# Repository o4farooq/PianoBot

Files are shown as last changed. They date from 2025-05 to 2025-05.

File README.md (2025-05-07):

# PianoBot 🎹 – Autonomous Piano-Playing Robot

PianoBot is an autonomous, LEGO-based robot capable of playing piano keys by interpreting color-coded sheet music. Designed and programmed by a team of three engineering students, the robot combines precise mechanical design, sensor integration, and custom CAD components to achieve smooth and accurate performance.

## 🔧 Overview

- 🎯 **Accuracy:** 92% success rate across 70 notes  
- 🤖 **Actuation:** Two robotic fingers driven by motors and 4 LEGO gears  
- 📏 **Precision Control:** Ultrasonic sensor ensures accurate key strike distance  
- 🎨 **Sheet Music Detection:** Color sensor reads and decodes color-coded notes  

## 🛠️ Key Features

- **Sensor Integration:**  
  Combines an ultrasonic sensor for dynamic range detection and a color sensor to parse visual sheet music input.

- **Mechanical Design:**  
  Robotic fingers with a 75-degree range of motion, powered by 2 motors and supported by a gear train, enabling controlled key presses.

- **Custom Components:**  
  CAD-modeled robotic fingers, motor mounts, and suction rollers designed in **SolidWorks** and **AutoCAD**, then fabricated via **laser cutting** and **3D printing**.

## 📐 Technologies Used

- **SolidWorks / AutoCAD** – Design and modeling of structural components  
- **Arduino (UNO R4)** – Microcontroller for sensor input and motor control  
- **C++ / ROBOTC** – Codebase for logic and motion control  
- **3D Printing / Laser Cutting** – Manufacturing of custom-designed robot parts  

## 🧠 Team & Purpose

This project was developed by a team of three second-year Mechanical Engineering students at the **University of Waterloo** as part of a robotics design challenge. The focus was on blending hardware design, motion control, and sensor feedback in a compact and functional prototype.

## 🔗 License

This project is open for educational and portfolio purposes. All CAD files and source code belong to the original team members.

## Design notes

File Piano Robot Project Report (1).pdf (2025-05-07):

# Piano Robot Project Report

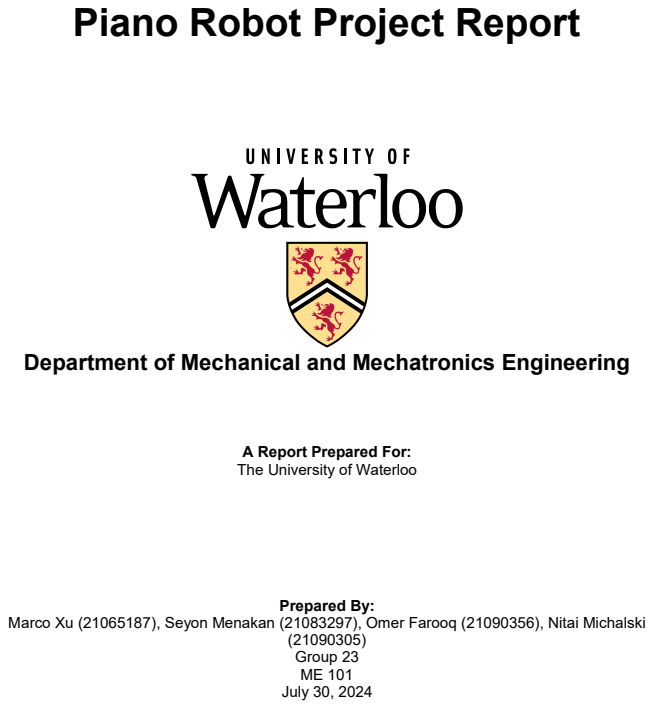
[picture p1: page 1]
Prepared By:; (21090305) Group 23 ME 101 July 30, 2024

Department of Mechanical and Mechatronics Engineering

A Report Prepared For:
The University of Waterloo

Marco Xu (21065187), Seyon Menakan (21083297), Omer Farooq (21090356), Nitai Michalski

## Table of Contents

List of Tables | Error! Bookmark not defined.

## List of Figures

Figure 17: Sheet music motor holder. The SolidWorks model can be found in appendix B, figure

Figure 18: Sheet music suck roller. SolidWorks model can be found in appendix B, figure 36. ..19 Figure 19: Sheet music compressive rollers. The SolidWorks model can be found in appendix B,

Figure 20: Bracket holding the two-color sensors. The AutoCAD model can be found in

Figure 51: Sketches of the suck roller (roller 1), tensioning roller (roller 2), and motor mount ....48

## Summary

This report covers the development of an autonomous robot designed to play the piano using an

EV3 robot controller and a color sensor to read sheet music. The primary goal of this project

was to create a robot that could read sheet music and play two octaves of a piano while staying under a $100 budget (excluding the EV3 robot cost). This document details the project’s

background, problem definition, technical progress, mechanical and software design,

verification, and project management. The motivation behind the robot was to showcase the

EV3 robot’s capabilities while creating a challenging project. The robot was designed to read

sheet music using color sensors, save played songs, and accurately press piano keys. The engineering specifications included cost constraints, safety, note-playing delay, sheet music

reading accuracy, and ease of setup. The final design featured a compact mechanism with color

sensors, a conveyor belt for feeding sheet music, and robotic fingers for pressing the keys.

During the conceptual design phase, the team brainstormed various solutions for the subfunctions of reading sheet music, saving songs, and pressing piano keys. The final design

combined the most feasible solutions, such as a fixed color sensor with rotating sheet music

and robotic fingers controlled by motors. Detailed sketches and CAD models ensured accurate and efficient mechanical design. Verification tests confirmed that the robot met all primary

functional requirements, including playing notes with minimal delay, accurately reading sheet

music, and effectively handling user input. The software design included functions for

configuring sensors, storing and reading note values, and controlling the robotic fingers. The project management section highlighted task delegation and adherence to the project plan.

Recommendations for future improvements included ensuring identical gears for the right finger,

making the design more symmetrical and visually appealing, using a larger keyboard, upgrading

motors for better performance, and enhancing the user interface for a more interactive experience. These enhancements would further improve the robot’s functionality, reliability, and

user experience. In conclusion, the project successfully achieved its objectives, and the report

outlines the next steps for continued development.

## 1.0 Needs Analysis

1.1 Background Description

The project aimed to create an autonomous piano playing system for the EV3 robot, capable of

playing notes on a keyboard based on sheet music. The robot would be able to save and play

songs, appealing to anyone who understands music, and presenting a challenging programming

and design challenge.

1.2 Needs Statement

A need exists for a robot to play all white keys of 2 octaves of a keyboard/piano while costing under $100 without including the cost of EV3 robot and any other given components. The

primary functional requirement is to play 2 full octaves of the keyboard from the low “C” note to the high “C” note. The primary constraint requirement is to build the piano robot with the given components and any extra components giving a total cost of under $100. The budgeting and

cost tracking will be highlighted in a later section.

1.3 Engineering Specification
Each specification is carefully designed to ensure the project meets its functional, safety, and

performance requirements [1]. The Engineering Design Specification for the project encompasses ten critical characteristics. Firstly, the cost is constrained to be less than $100.00

CAD, which will be verified through analysis by totaling the receipts of any additional expenses.

Secondly, safety is a key constraint and is paramount; it is verified through demonstrations to

ensure there are no pointy edges, pinch points, or potential fire hazards. Thirdly, a functional requirement is that the system must play notes with minimal delay, specifically less than one

second. This characteristic will be tested using a stopwatch to measure the delay between key

presses, calculating the difference between the highest and lowest delays. Furthermore, the

ability to play modified sheet music will be examined by having an experienced pianist cross-check if the notes are played correctly. Another functional requirement is for the sheet music

reader to read the color sensor combinations with an 80% accuracy at least which can be

verified by outputting the notes onto a .txt file or onto the console and having someone cross-

check with the predetermined color sensor combinations. A functional requirement that must be considered is the range of the notes being played, which is from Low C to High C. This is

exactly two octaves and only the white keys will be played. This can be verified from making the

robot play the C major scale on two octaves, which will therefore hit every key from Low C to

High C. A non-functional requirement for the system is that it should be easy to set up. The

robot should be assembled every time without damage to the components, and without any of the components falling out of place. A functional requirement to consider is the maximum

amount of notes the robot can play, which is limited to 70 notes. This is because as the robot

plays notes using over a longer period, the robot becomes more and more inaccurate with the

angles needed to hit each individual key. This can be verified by making the robot play a .txt file with over 70 notes and see if the robot completely stops playing at 70 notes. Moreover, user

input is also a functional requirement to increase the robot’s enjoyability. The design can

accomplish this by using button controls that manipulate the robot’s functions. This is verified

through demonstration of how pressing the buttons controls the actions of the robot. The final requirement is the constraint requirement of the mass of the robot weighing less than 3 kg. This

can be verified by using a scale to measure the entirety of the robot.

## 2.0 Conceptual Design

2.1 Morphological Matrix

Figure 1: Morphological Matrix

The piano robot’s subfunctions include reading sheet music, saving the song as a.txt file, and

pressing piano keys with robotic fingers. Three solutions were considered: vertical color sensors, horizontal and vertical sensors, and fixed sensors. The chosen solutions balanced

efficiency, cost, and complexity, ensuring the robot could effectively read sheet music.

2.2 Conceptual Designs Considered

These three designs were the conceptual ones formulated during the initial stages of the design

process. Each design contributed various components that were incorporated into the final

product. However, it primarily utilizes the most effective concepts from conceptual designs 2 and 3, which eventually resulted in the final product.

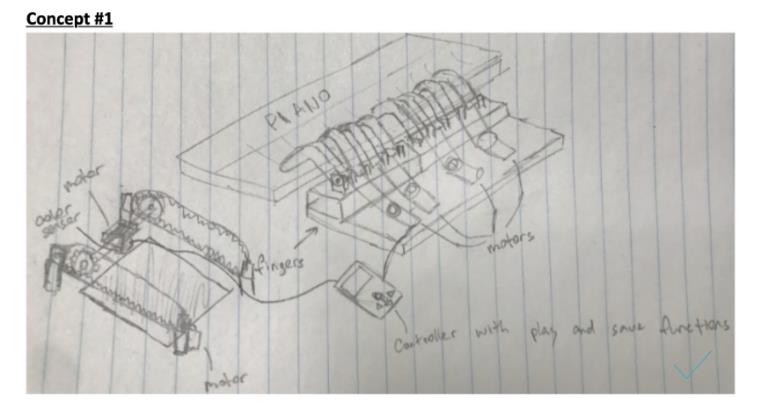
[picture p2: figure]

Figure 2: Conceptual Design 1

The first conceptual design was the inspiration for the sheet music reader. More specifically, the

drawing shows a design utilizing suction rollers to roll the sheet music beneath the color sensor.

The color sensor reads the colors on the sheet music and translates them into notes to be

played by the robotic hand. Furthermore, the fingers of this design are not accurate to the final design, as it consists of multiple fingers, while the final design only has two fingers. This is one

main difference between the conceptual design and the final product. Finally, the controller in

this conceptual design was used for the same purpose in the final design, which was to operate

and save songs that were already played.

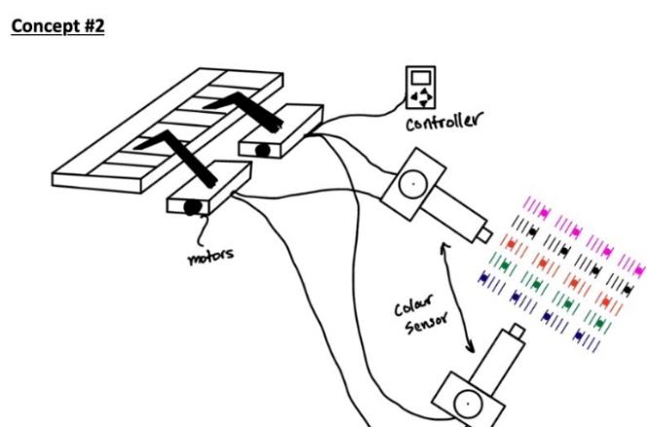
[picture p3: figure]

Figure 3: Conceptual Design 2

The second conceptual design served as the inspiration for the robot’s fingers. The final product mirrored this design, featuring two separate robotic fingers, each supported by two motors and

controlled through the controller. This configuration allowed for precise and independent

movements of each finger, enhancing the robot’s ability to perform complex tasks. Furthermore,

the color reader, which was part of this design, proved to be somewhat accurate in its function. However, it didn’t include specifications for the suction roller and conveyor belt design used for

the sheet music, which were later incorporated into the final design of the robot. These

additional components were essential for the accurate handling and processing of sheet music,

ensuring smooth operation. Overall, this conceptual design was primarily used for robotic fingers, significantly influencing the development of the final product and contributing to its

overall functionality and effectiveness.

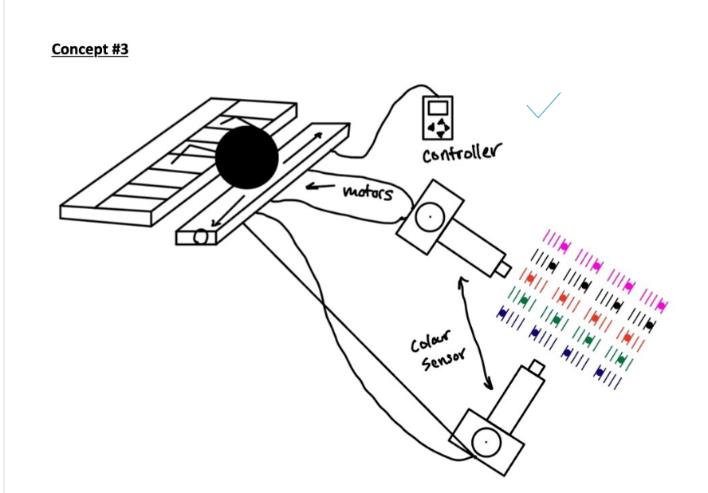
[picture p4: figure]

Figure 4: Conceptual design 3

The final conceptual design proved impractical due to the difficulty of creating a rolling mechanism

that kept the robotic fingers in place for accurate key strikes. Balancing the mobility of the base with the stability and precision of the fingers was complex. Maintaining smooth and consistent

motion without the fingers shifting was essential for accuracy, making the design challenging to implement and impractical for real-world application without significant modifications.

2.3 Decision Making Matrix

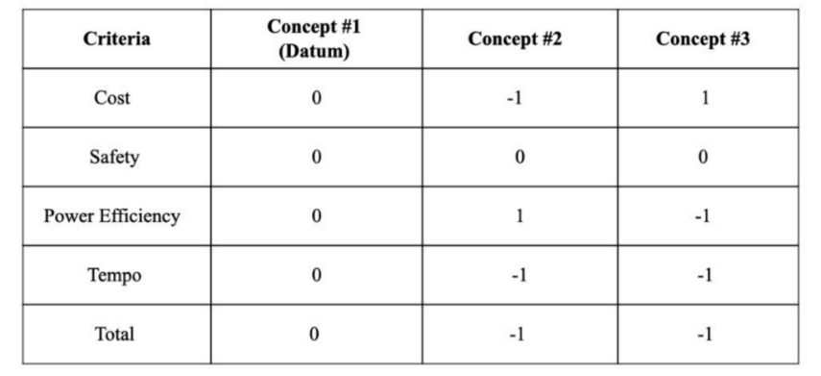
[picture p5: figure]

Figure 5: Decision Making Matrix

The decision-making matrix essentially evaluates the feasibility of each conceptual design by

ranking each important requirement (e.g., cost, safety, etc.). It ranks each requirement based on

the following criteria: +1 being better, 0 being mediocre, and -1 being not as good. Moreover, the total score is summed up at the end, and the conceptual design with the highest score is expected

to be the most feasible.

From the above, conceptual design 1 is the most feasible as it has the highest score of zero, while the two other conceptual designs both got a score of negative one. However, the final decision

was made to proceed with the second conceptual design for the note-playing section of the robot

because the first conceptual design was too simple. As for the robot’s music reader section, a

new design was needed as the current designs may be too difficult to do and limit the sheet music’s size. This new design will be detailed in the next section.

2.4 Updated Mechanism Designs
For the sheet music reader part of the robot, a new design was created with a compact Tetrix

frame, where a motor, mounted to the Tetrix frame, turned a suck roller. This suck roller would

pull in the sheet music, assisted with two free-rolling rollers which would keep the sheet music

properly tensioned. A color sensor bracket would hold two color sensors in place, which would read the sheet music as it is being pulled by the suck roller. This design can be seen below, in

figure 6.

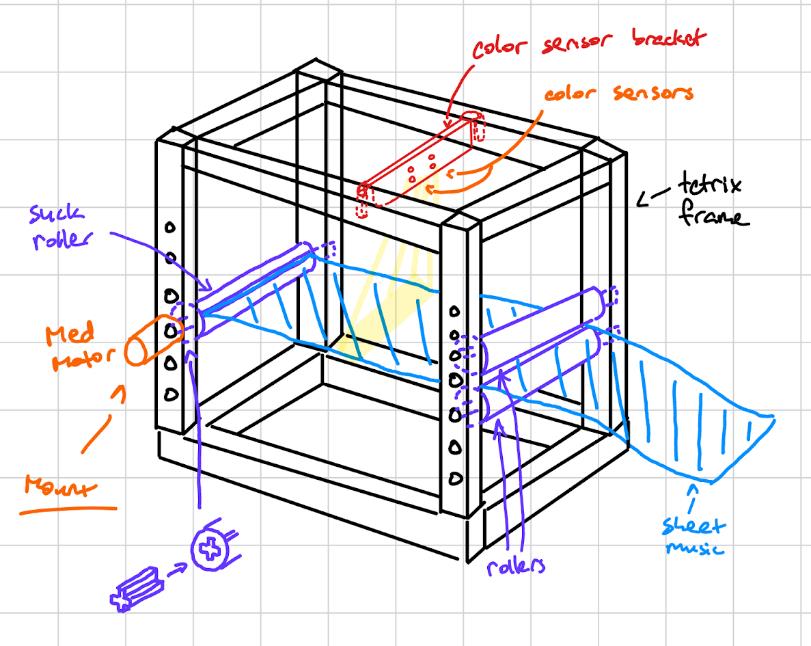
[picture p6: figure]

Figure 6: New sheet music reader design

For the note-playing part of the robot, a more detailed design of the arm movement mechanisms

was created, as seen in figure 7. There would be one motor to control the horizontal rotation of

the arm (to move to different keys) and another motor to control the vertical rotation of the arm (to press down on the key). The horizontal rotation motor had a gear attached to it, which

meshed with another gear, which had an arm mount/base attached to it. This arm mount/base

held the arm (with a gear attached to it), along with the vertical rotation motor (with a gear

attached to it). This meant the vertical rotation motor would rotate horizontally with the arm while it is operating.

Figure 7: Design of the arm movement mechanisms

Additionally, a recalibration system was to be implemented. Two ideas were considered for the

recalibration method: an ultrasonic sensor for each arm to detect the distance of the arm as it rotates, or a touch sensor for each arm to detect when the arm reaches a certain point.

Ultimately, it was decided that the touch sensor method would be more reliable as the ultrasonic

sensor could pick up unreliable readings due to the way the arm rotates. The recalibration

function would involve the arm rotating until it pressed the touch sensor, at which point, the robot would know the exact position of the arm and would re-position the arm in its starting

position.

2.5 Individual Part Designs
Sketches were made for parts that needed to be 3D-printed or laser-cut (appendix E), which

included the suck roller, tensioning rollers, motor mount, color sensor bracket, and fingers.

These sketches provided a rough starting idea for the CAD design and only had some rough dimensions.

For the tensioning rollers, the pegs at the ends of the roller were meant to fit in the Tetrix holes

and be able to freely rotate. The size of the rollers was chosen so that two rollers next to each

other in the Tetrix frame would result in a very small gap.

The suck roller had the same dimensions as the tensioning rollers, except for two changes: a

slot for sheet music and a cross-shaped hole on the end of one of the pegs for a Lego axle to be inserted in. The cross-shaped hole would allow the motor to connect to the suck roller and

rotate it.

The motor mount was designed to serve two purposes: hold the motor in place and mount to the

Tetrix frame securely. Only a rough concept sketch of the motor mount was created; the actual

design of the motor mount was to be adjusted during the CAD modelling stage.

For the color sensor bracket, it needed to be able to fit on the Tetrix frame without moving. Two pieces at the ends of the bracket would be inserted into the Tetrix frame holes. In the middle of

the bracket, there would be four holes for the color sensors to mount to.

For the finger, a realistic finger shape was desired. Some cross-shaped holes were included so

that it could be attached to the arm mount/base. The finger should also be thin so that it can play between the black keys.

## 3.0 Mechanical Design

3.1 Layout
The primary robot, designed using Lego and laser-cut parts, holds a piano and presses its keys. It has two individual Lego beams that pivot sideways while also moving up and down

vertically to hit the piano keys. These arms are powered by two sets of motors and gear

systems for each robotic finger. As seen below in figure 8, the larger motors and gears on the

base control the rotation of the robotic arms along the horizontal axis. These motors are connected to a rectangular base and two rectangular prisms as shown in figure 9. Supporting

beams secure the motors to the axle, and the right arm has one side of the robot also includes

an additional stopper to limit the finger’s vertical motion of the finger upwards. On the other

design, the finger’s upward motion is limited beyond a certain point by the bottom edge of the finger, as it presses against the base of the axle holder on the rotating structure. This is visible

in figure 10:

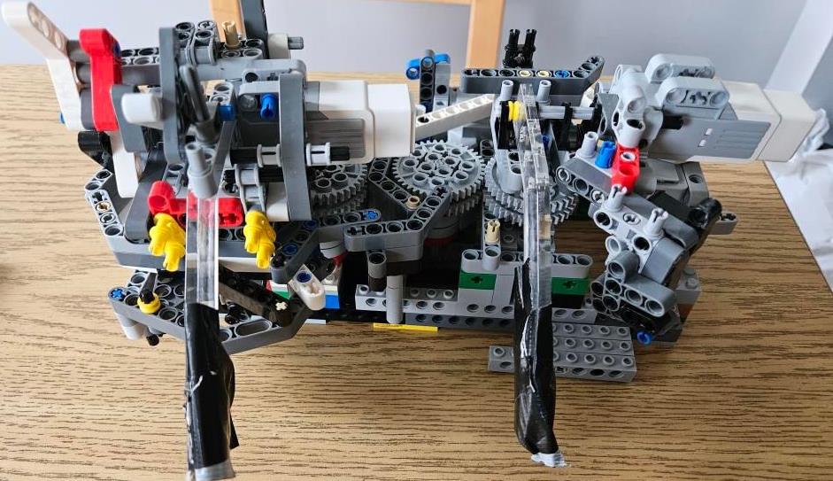
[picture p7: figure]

Figure 8: Top view of piano-player

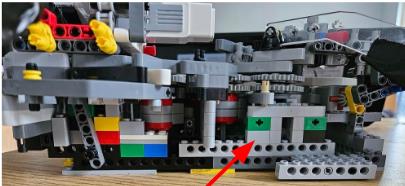
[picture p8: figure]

Figure 9: Front view of piano-player showing the rectangular base

Figure 10: Side view of finger axle

The gear attached to the motor is held tightly in place with the gear attached to the moving

structure through Lego walls that push them together from each side. The rotating base that

houses the finger is attached to one of the gears, which allows the finger to move in an arc between each key. Each moveable base also includes a smaller motor attached directly to the axle which moves the fingers up and down to press each key. This design allows the motors to

be rigidly attached and provide enough downward force. As shown in figure 11, the robot fingers themselves were laser cut from acrylic, which provided high strength while also being relatively

light. This allowed the fingers to withstand the higher forces required to press down some of the

further keys at wider angles. The fingers were also cut to angles and lengths to press down

each key with maximum force, while also limiting its range of motion past the necessary requirements to hit the furthest keys. Piece of cardboard were also duct taped to the edges of

the fingers to remove the unpleasant noise that resulted from the acrylic striking the keyboards

plastic keys. These fingers included cross-shaped cuts in the exact shape of the axle to fit

tightly, with small tolerances. This allowed the fingers to be powered by the motor attached to the axle from the other side, while remaining rigid when higher power was used on the motor. In

front of the robot is a rectangular base that holds the piano in place. As shown in figure 12, the

user can easily place the piano in the correct spot during each use by placing the piano in a way

that holes on each piano fit into cylindrical Lego prices from each corner. This ensures the piano is placed in a position that allows the fingers to reach each key.

Figure 11: Robotic finger. The AutoCAD model can be found in appendix B, figure 40.

Figure 12: Robot piano base

One of the issues in the original design was the rigidity of the moveable base structure, and its

ability to withstand reaction forces that resulted from pressing down each key. When the robot

attempted to press down certain keys, especially further ones at larger angles, the base holding

the finger and its base would move upwards, instead of pressing the keys downwards. This was solved using two separate methods. Firstly, the gear attached to the base structure that held the

finger and its motor was attached to an axle, which was then fed through 2 different holes through pieces attached to the main base that held the gear structure. The base gear and axle

structure are shown in figure 13. Also, the axle was held in place from moving up or down using

a small Lego axle holder and a small, but thick, unused Lego gear that fit tightly on the axle.

This ensured that the gear was held in place, and only rotated, without any up or down movements off its base. After the moveable base itself was secured tightly, the finger and axle

attached to the base also needed to be secured, since they moved upwards when the keys

were pressed down. This was accomplished by building a guide rail around each of the rotating

bases, attached to the bottom base of the robot. Extruding Lego pieces were then added to the moveable bases which moved on top of the guide rail. This ensured that the upwards reaction

force from pressing down the keys were counteracted by the guide rail that held in place the

base and the finger attached to them. These components are highlighted in figures 14 and 15.

This improved rigidity allowed the robot to completely press down the keys, while also using less motor power, since less energy was lost through movements within the robot itself.

Figure 13: Gear and axle for rotating base

Figure 14: Guide rail on the outer side

Figure 15: Extrusion that moves along guide rail

For the music sheet reader, a cube-like design was created with four vertical beams on each

side, as shown in figure 16, and described in the previous section. Unlike robotic arms, this

design was built using Tetrix parts, as well as laser cut, and 3D printed components. In this

design, a motor was used to turn a 3D printed conveyor belt which took the fed paper sheet music in a thin slot. The motor was attached to the frame using the holder show in figure 17.

This suck roller was alongside two free-rolling rollers that helped keep the sheet music properly

tensioned and aligned in place for the color sensors. The suck roller and compressive rollers are

shown in figures 18 and 19. These two color sensors were attached to the frame using a laser cut bracket that fit into the Tetrix frame, shown in figure 20. This allowed the two color sensors

to be positioned to read the left and right sides of the sheet music, while also being properly

tensioned to keep the colored sheet music straight, while also feeding at the appropriate speed.

Figure 21 shows the sheet music being fed into the sheet music reader.

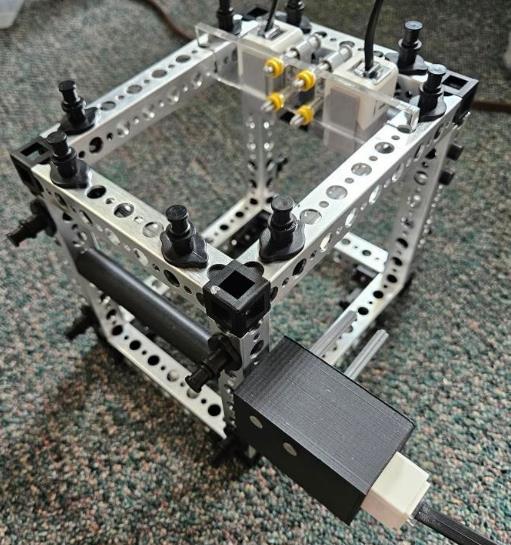
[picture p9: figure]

Figure 16: Music sheet reader

Figure 17: Sheet music motor holder. The SolidWorks model can be found in appendix B, figure 37.

Figure 18: Sheet music suck roller. SolidWorks model can be found in appendix B, figure 36.

Figure 19: Sheet music compressive rollers. The SolidWorks model can be found in appendix B, figure 36.

Figure 20: Bracket holding the two-color sensors. The AutoCAD model can be found in

appendix B, figure 39.

Figure 21: Sheet music reader pulling in sheet music.

3.2 Functions

There are a multitude of functions for the piano robot that all need to be met for it to successfully

operate. Furthermore, the functions of this robot were generalized into 6 main functional

requirements that had to be met for a successful final product. These included:

i. The robot should be able to successfully play the notes with minimal time delay
ii. | The robot should be able to read and play the colored sheet music
iii. | The robot reads in the color sensor combinations successfully
iv. | The robot should have a range of notes that spans roughly two octaves
v. The maximum amount of notes a robot can play in a song should be 70

vi. The robot should be able to handle user input successfully (via the EV3 controller)

The robotic fingers’ ability to move between notes quickly (Function I) was achieved through a

lightweight design and precise angle measurements. The conveyer belt design for the sheet

music (Function II) allowed the color sensor to register each note, with software ensuring accurate note correspondence. The optimal speed for the sheet music to roll beneath the color

sensor (Function III) was found using suction rollers to impose tension. Stability of the robotic

arms (Function IV) was ensured by the pivot of the gears, arm length, and a stable Lego base.

The note-reading limit (Function V) was enforced through software, tested with a 70-note song. Finally, a straightforward coding solution (Function VI) generated a user interface on the EV3

controller for saving, playing, or exiting the program.

## 4.0 Verification of Design

4.1 Line by Line Verification
The following table consists of the engineering design specification and the method of testing for

each specification.
Table

Table 1: Line by Line Verification of Engineering Design

No. | Characteristic | Relation | Value | Units | Verification Method | Comments
1 | Cost | < | 100 | $, CAD | Analysis | Total the receipts of additional costs
2 | Safety | N/A | N/A | N/A | Analysis | Ensure there are no pinch points, pointy edges, or potential fire hazards
3 | Plays notes with minimal delay | < | 1 | s | Test | Use a stopwatch to measure minimal delay between each key press, then take the difference between the highest and lowest delays
4 | Plays modified sheet music | N/A | N/A | N/A | Examination | Have an experienced pianist listen to the played notes and verify that the robot is playing the correct notes
5 | Reads the color sensor combinations accurately | ≥ | 80 | % | Test | Output the notes read from the sheet music reader onto a .txt file or onto the robot’s console cross-check with the predetermined color sensor
6 | Range of notes | = | 2 | octaves | Test | Make the robot play the C major scale on two octaves, which will therefore hit every key from Low C to High C

7 | Easy setup | N/A | N/A | N/A | Demonstration | While assembling the robot, show that the system is assembled every time without damage to the components, and any components falling out of place
8 | Maximum amount of notes the robot can play in a song | = | 70 | notes | Test | Make the robot play a .txt file with over 70 notes and see if the robot completely stops playing at 70 notes
9 | Robot includes user input | N/A | N/A | N/A | Demonstration | Have volunteers press buttons on the robot to control its actions which will therefore display user input
10 | Mass of the entirety of the robot | < | 3 | kg | Test | Use a scale to measure the entirety of the robot

The verification results are as follows:
1) After totaling all receipts, the final cost is $44.00 which is well below the maximum cost

planned for this project

2) After running through the robot’s physical mechanism, there are no pinch points, pointy

edges or potential fire hazards that came across the PianoBot
3) After taking measurements using the stopwatch, the highest delay was 0.94 seconds

and lowest delay was 0.52 seconds, giving a delay well under 1 second

4) After running modified sheet music through the sheet music reader, the PianoBot was

able to play those corresponding notes
5) After making the robot read the sheet music, the group calculated the number of notes

that were correctly read and divided it by the total notes that were read. This gave a

value of 87%, which was over the target of 80%
6) After testing the robot with the C major scale, it was shown to play 2 full octaves from

Low C to High C

7) After countless times of setting the robot up, it was time and time again demonstrated

that none of the components slipped off or broke

8) After making the robot read a .txt file with over 70 notes, the robot only played 70 and stopped after the 70th note, proving the test correct
9) After having volunteers test out the robot on demo day, the user input aspect is fulfilled

using buttons either playing a different .txt file or saving read notes into a .txt file

10) After weighing the entire robot structure, the total mass came out to be 1.947 kg which is

well under 3 kg.

4.2 Assessment of Verification
After running through all the verification tests for all functional requirements, non-functional

requirements, and constraint requirements, it is safe to say that the design works as it passed all the tests and fulfilled all requirements. While it does not play the piano or read the notes with

100% accuracy, it fulfilled all predetermined goals and therefore is a success.

## 5.0 Software Design and Implementation

5.1 Overall Software Operation

The software operates by starting with the user pressing the enter button, recalibrating the arm, and then prompting the user to press a button. If the button is pressed for under 3 seconds, the

sheet music reader plays the music, if it's held for 3 seconds or more, the note values are saved,

and the program shuts down. The flow chart in the Appendix explains the process.

5.2 Robot Task List

The robot task list is as follows:

Startup:

- Configure all sensors.
- Run arm re-calibration function.
- Arm spins until a touch sensor is hit, ensuring the position of the arm is calibrated.
- Display on controller screen: “Press enter button to play music from sheet music. Press up/down/left/right buttons to play saved music. To exit the program, hold the enter button.”

Operation:

- User presses the enter button.
- Turn on the motor that connects to the suck roller.
- Two colour sensors detect two colours from the sheet music, which are translated into a note value that is associated with an angle for the arm motors to rotate.
- An arm motor rotates so that the finger hovers over the note that corresponds to the colour combination detected by the colour sensors.
- When a certain colour combination is detected (eg. black and black), this means the song has ended
- Display on controller screen: “Hold up/down/left/right buttons to save the song. Press up/down/left/right buttons to play saved music. Press enter button to play music from sheet music. To exit the program, hold the enter button.”
- If any of the up/down/left/right buttons are held:
- Save the note values into a text file.
- Display on the controller: “Song saved to up/down/left/right button slot.”
- Display on controller screen: “Hold up/down/left/right buttons to save the song. Press up/down/left/right buttons to play saved music. Press enter button to play music from sheet music. To exit the program, hold the enter button.”
- If any of the up/down/left/right buttons are pressed:
- Read the note values from the associated text file and play the song.
- A finger motor rotates so that the finger presses down on the note, then rotates the opposite way so that the finger returns to its previous position.
- The robot will run the arm re-calibration function
- Display on controller screen: “Hold up/down/left/right buttons to save the song. Press up/down/left/right buttons to play saved music. Press enter button to play music from sheet music. To exit the program, hold the enter button.”

Shutdown Procedure:

- If the enter button is held:
- Display on controller screen: “Skee-yee” and “EEEEEE”
- Exit the program.

5.3 How Overall Code was Separated

The code was divided into smaller parts based on different functions, such as recalibration, which

was separated from the rest to avoid confusion. The group used at least 6 non-trivial functions to

separate repetitive or self-performing parts.

5.4 Functions Breakdown
Table 2: How Each Function Works
Function | How it Works | Programmer
void configureAllSensors(); | A modified version of the configureAllSensors function from Professor Carol Hulls. For the source code, see appendix A, figure 24. | Marco Xu
void storeValue (short * tempStoredValues, short * colour1, short * colour2, int noteIndex); | Uses the two color sensor readings to determine the corresponding note value, then stores it in the tempStoredValues array. For the source code, see appendix A, figure 25. | Nitai Michalski
void readAndStore(short * tempStoredValues, short * colour1, short * colour2); | Reads the sheet music and calls the storeValue function. For the source code, see appendix A, figure 26. | Omer Farooq
void rotateArmAndPlay(int angleNew, int angleOriginal, int noteValue, short * timeHold); | Based on the note value, it decides which arm to rotate (left or right). Then, depending on the arm's position, it rotates clockwise or counterclockwise to the key, then plays the key. For the source code, see appendix A, figure 27. | Marco Xu
void playFromFile(TFileHandle & fin, short * angle, short * timeHold); | Reads in note values from a file, then calls the rotateArmAndPlay function. For the source code, see appendix A, figure 28. | Seyon Menakan
void playFromReader(short * tempStoredValues, short * angle, short * timeHold); | Reads in note values from tempStoredValues array, then calls the rotateArmAndPlay function. For the source code, see appendix A, figure 29. | Seyon Menakan
void arrayToSaveFile(TFileHandle & fin, short * tempStoredValues); | Writes note values from the tempStoredValues array to a file. For the source code, see appendix A, figure 30. | Omer Farooq
void buttonOptions(TFileHandle & saveUp, TFileHandle & saveLeft, TFileHandle & saveDown, TFileHandle & saveRight, short * angle, short * timeHold, short * tempStoredValues); | Based on how long a button is held, it runs the playFromFile function or arrayToSaveFile function. The button being pressed determines the parameters in the function call. For the source code, see appendix A, figure 31. | Nitai Michalski
bool playOrSave(TFileHandle & saveUp, TFileHandle & saveLeft, TFileHandle & | Based on button input, it calls the readAndStore function and the playFromReader function, or the | Marco Xu

saveDown, TFileHandle & saveRight, short * angle, short * timeHold, short * tempStoredValues, short * colour1, short * colour2); | buttonOptions function. Holding the enter button causes the function to return true, so that the loop in the main program exits. Otherwise, the function will return false. For the source code, see appendix A, figure 32.
void recalibrate(); | Recalibrates the left arm by rotating the arm until it hits the touch sensor, then rotating the arm to its starting position. Initially, both arms were to be recalibrated with a touch sensor for each arm, but due to a port shortage, only the left arm would be recalibrated with a touch sensor, and the other arm would just be manually recalibrated. For the source code, see appendix A, figure 33. | Seyon Menakan
void displayMenu(); | This function essentially displays the menu with the different options to the user. This includes saving the song, playing a saved song or quitting the program. For the source code, see appendix A, figure 34. | Omer Farooq

5.5 Data Storage

This program stores data in arrays or.txt files. The colour1 and colour2 arrays determine note

values for sheet music reading. The tempStoredValues array stores note values from the sheet

music reader or notes in.txt files. The angle and timeHold arrays determine the robot's finger movement and time holding piano keys. SaveUp, saveLeft, saveDown, and saveRight .txt files

store note value data for buttons held for 3 seconds or more.

5.6 Software Design Decisions
One software design decision implemented was saving memory by turning the array values

from integers to shorts. Due to having a large code with a lot of saved data, when having int

arrays, the memory of the Lego EV3 robot becomes full. Therefore, by significantly reducing the memory sizes of the arrays, the group managed to clear wasted memory space. Another

decision used was how to read the color sensor combinations. The group decided to store the

values by using two color arrays and to run through a loop where both arrays would match and

give an index value which becomes the note value.

5.7 Code Testing

The configureAllSensors function was tested by first turning on the suck roller motor, which was connected to the motor multiplexer, at a speed of 10 without calling the configureAllSensor

function. Without the configureAllSensors function, the motor should only be able to turn at max speed. After making note of the motor speed, the program was modified to call the

configureAllSensors function before turning on the suck roller motor at a speed of 10. The motor turned significantly slower in the second test than the first test, showing that the

configureAllSensors function was properly configuring the suck roller motor. The other sensors

were assumed to be properly configured as they were just a modified version of the

configureAllSensors function written by Professor Hulls.
Next, the displayMenu function was tested by calling the function and checking the robot

controller display. It was verified that the function was working properly when the menu text was

properly displayed on the controller screen and it was erased after a short delay.

After, the arrayToSaveFile function was tested by having the function read a pre-defined tempStoredValues array and write the numbers from the array into a file. The program was run,

the file on the robot was checked, but the numbers were not on the file. The issue turned out to

be because the file was not closed in between converting the file from read-only to write-only,

and vice versa. After making these changes, the numbers were on the file, as expected. Similarly, the buttonOptions function was tested by having a pre-defined tempStoredValues

array and calling the arrayToSaveFile function. After running the program, the file on the robot

was checked, which showed the numbers from the array on the file.
The storeValue function was tested by adding test code to display the note value after it was

found. The color sensors were held over a set of colours, then the program was run, and the

note value displayed was checked with the spreadsheet.

The playOrSave function and readAndStore function were tested together. First, holding the enter button for more than three seconds ended the program, which was the expected result.

Next, the reading and storing functionality was tested by holding the enter button for less than

three seconds. The suck roller motor was turned on until it reached the end of the sheet music.

There were some issues with the motor stopping before the end of the sheet music or continuing after the end of the sheet music, but these were resolved by increasing the

tensioning on the sheet music and changing the position of the color sensors in relation to the

sheet music. The note values were read and stored in the tempStoredValues array. Then, the

up button was held (which called the buttonOptions function), transferring the values from the tempStoredValues array to the saveUp file. The file was checked, and the numbers on the file

were compared to the spreadsheet containing the correct numbers. After resolving tensioning

issues and reading issues, the numbers were mostly correct. The incorrect numbers were likely

caused by suboptimal setup of the color sensors in relation with the sheet music.

The recalibrate function was tested by ensuring that the robot hit the touch sensor, then

returned to its starting position. A couple angle measurements were needed to ensure the robot consistently rotated to its starting position.

The rotateArmAndPlay function was tested together with the playFromFile and playFromReader

functions. The enter button was pressed to activate the sheet music reader. Next, the

playFromReader function was called, which used the rotateArmAndPlay function to play the notes. After ensuring that the arm was moving to the keys as expected, the up/down/left/right

buttons were pressed to call the playFromFile function, which also used the rotateArmAndPlay

function to play the notes. It was verified that the arm was moving to the keys as expected.

Finally, the entire program was tested. After configuring the sensors, recalibrating, and displaying the menu, the enter button was pressed, which activated the sheet music reader.

After the sheet music reader finished reading, the robot played the notes that were read by the

sheet music reader. When the robot finished the song, it recalibrated and displayed the menu.

The up button was held to save the song into the saveUp slot. The up button was pressed to replay the song. Next, the left, right, and down buttons were pressed to play the song saved in

those slots. Finally, the enter button was held to exit the program. These functions were

performed as expected, concluding the test of the robot.

5.8 Problems Encountered and Solutions
The testing process faced issues with color sensor combinations, which led to inaccurate

results. To address this, a timer was used to stop the motor in the middle of color boxes, increasing accuracy to over 85%. The angles array was also problematic, with sometimes

inaccurate angles for each note. Troubleshooting included using a console display message to

fix logic errors and ensure smooth code execution.

## 6.0 Project Management

6.1 Task Delegation
The following table displays the tasks each person of the group did:

Table 3: Task Delegation

Group Member | Tasks
Marco Xu | • Created all SolidWorks drawings • 3-D printed all components • Created sheet music color combinations

| • Created modified configure sensors function • Created rotate arm and play function • Created play or save function • Contributed to task main code • Contributed to report writing
Nitai Michalski | • Worked on piano playing mechanism of PianoBot • Helped 3-D print all components • Created sheet music color combinations • Created store values function • Created button options function • Contributed to task main code • Contributed to report writing
Omer Farooq | • Worked on sheet music reader mechanism of PianoBot • Helped laser cut all components • Printed out the sheet music • Created read and store function • Created array to save file function • Created display menu function • Contributed to task main code • Contributed to report writing
Seyon Menakan | • Created all AutoCAD drawings • Laser cut all components • Created sheet music • Created play from file function • Created play from reader function • Created recalibrate function • Contributed to task main code • Contributed to report writing

6.2 All Schedule Revisions
When first creating a schedule, the group created a Gantt’s chart to plan times to do specific

parts of the project. The image under is the Gantt’s chart first determined:

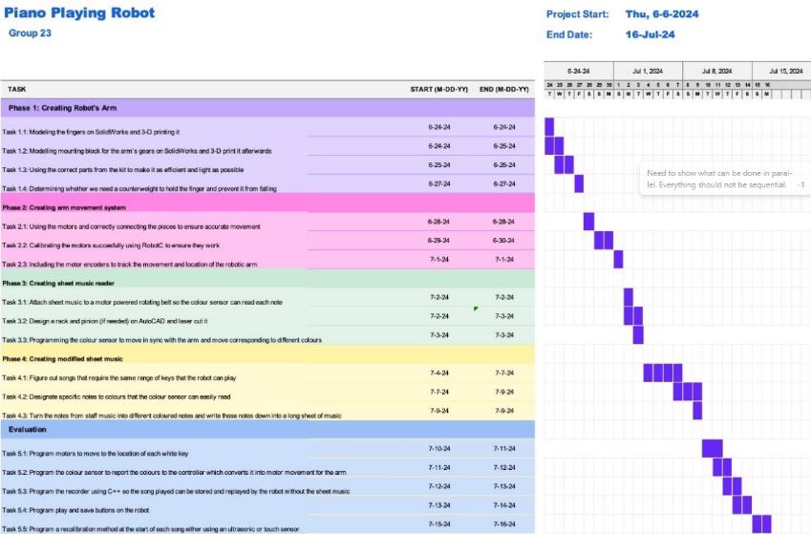
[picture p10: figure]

Figure 22: Gantt’s chart

The group faced a significant issue with the Gantt chart due to changes in design components over time. They decided to create a more accurate schedule to align with the current project

plan.

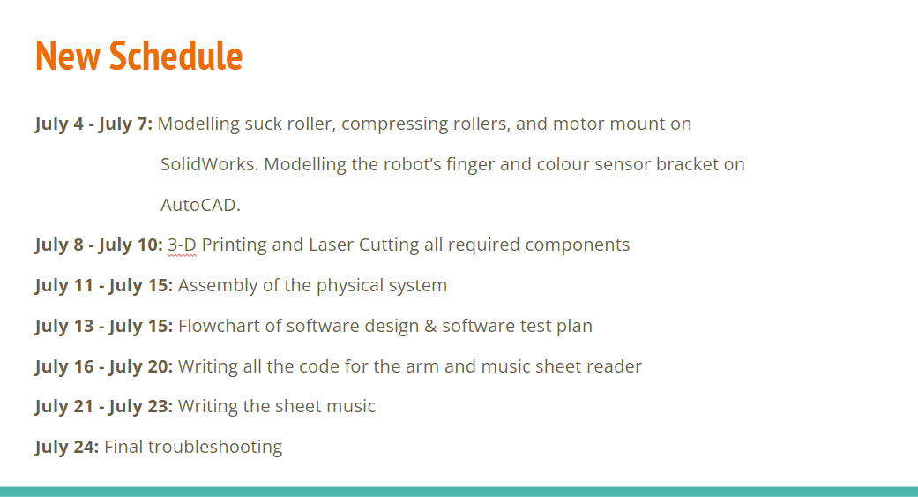
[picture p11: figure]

Figure 23: Updated schedule

This schedule was used for the remainder of the project working period and it was because of

this schedule that the group was able finish the project successfully.

6.3 Project Plan vs. Actual Plan
The first project plan differed from the most updated one as with the newest one, the

components were fully determined and the design outline was finalized whereas for the initial

plan illustrated in the Gantt’s chart, some components were still undecided upon. For example, one idea was to use a rack and pinion which was scheduled to be created in the Gantt’s chart.

However, after spending more time gathering ideas for the design, the group decided that the rack and pinion will not be used for the final design and therefore does not need to be created.

Moreover, working on this project for a bit every single day was not ideal but was laid out in the

Gantt’s chart. With the improved schedule, there would be a range of days when the task would

have to be completed, which was ideal for the group’s busy schedules.

## 7.0 Conclusion

Throughout this project, a robot was created that can play two octaves of a piano while costing less than $100. The PianoBot can also read modified sheet music and can store songs into .txt

files that can be played on command. The songs can consist of any notes in a 2 octave range

from Low C to High C but must be 70 notes in length. The design also consists of over 80%

accuracy of reading the notes. The design does not fall apart while setting up and weighs much less than 3 kg. Therefore, it can be concluded that the final design met the requirements

insisted upon.

## 8.0 Recommendations

As you take over the work on the piano playing robot, it's essential to identify areas for

improvement and outline the next steps to enhance the project's success. Here are several key areas where advancements can be made:

1. One of the critical improvements needed is ensuring that the gears for the right finger

are identical. This will help them align properly, resulting in smoother and more precise

movements. Utilizing 3D printing technology can facilitate the creation of these gears with high accuracy and consistency.

2. To enhance the overall functionality and aesthetics of the robot, it is important to align

the fingers correctly and clean up the design. Both sides of the design should be made more like maintain symmetry. This not only improves the robot's performance but also its

visual appeal and structural integrity.

3. Expanding the piano keyboard can significantly reduce issues related to hitting the

keys accurately. A larger keyboard provides more space, allowing the robot to maneuver its fingers more effectively without the risk of missing or striking multiple keys

simultaneously.
4. Upgrading to stronger motors can address the issue of momentum when hitting the

keys. More powerful motors will ensure that each key is pressed with the necessary

force, improving the accuracy and consistency of the robot's performance. This

enhancement is crucial for playing more complex and dynamic pieces.
5. The current user interface can be made more interactive and feature rich.

Enhancements such as the ability to remix songs, alongside an overall cleaner and more

intuitive design, will provide users with a better experience. Improving the UI not only

makes the robot more user-friendly but also opens new possibilities for creative expression and customization.

By focusing on these key improvements, you will be able to advance the functionality, reliability,

and user experience of the piano playing robot. Aligning the gears and fingers, working with a

larger keyboard, upgrading the motors, and enhancing the user interface are crucial steps that will contribute to the project's success. Your efforts in these areas will pave the way for future

innovations and ensure that the robot reaches its full potential.

## References

[1] “ME 101 project S24 - final report and demonstration details” https://learn.uwaterloo.ca/d2l/le/content/1021051/viewContent/5537825/View. (accessed 30 July 2024.)

## Appendix A: Source Code

Figure 24: Files included and global constants.

Figure 24: Configure all sensors function

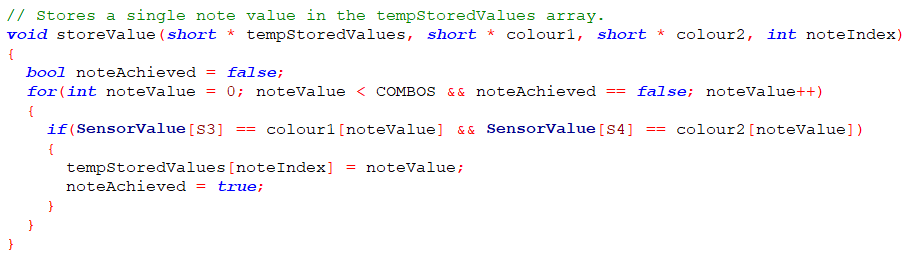
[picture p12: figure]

Figure 25: Store value function

Figure 26: Read and store function

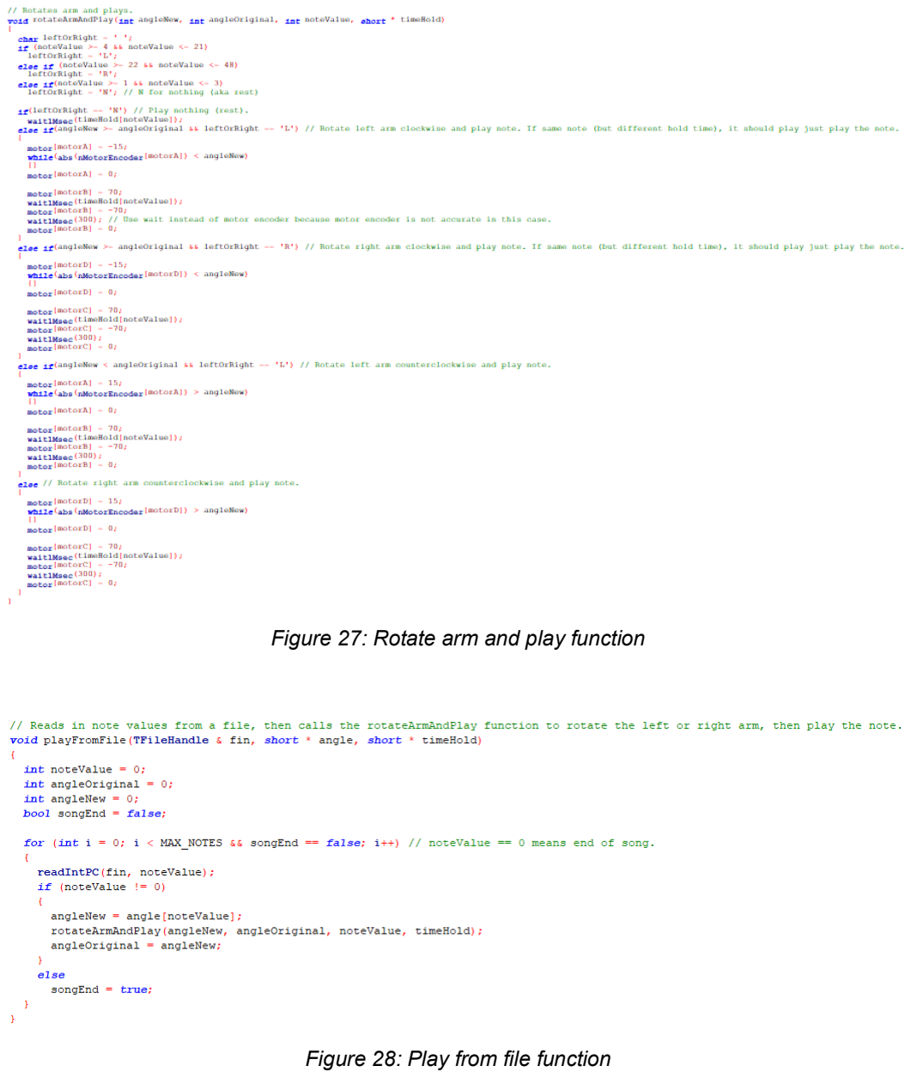
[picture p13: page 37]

Figure 27: Rotate arm and play function

Figure 28: Play from file function

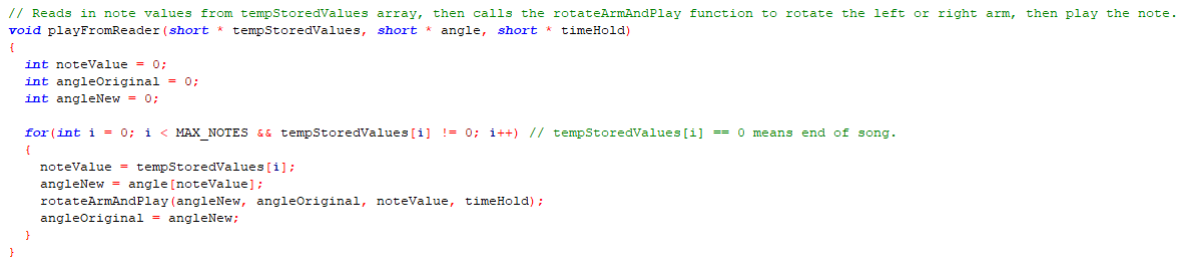
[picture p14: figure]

Figure 29: Play from reader function

Figure 30: Array to save file function

Figure 31: Button options function

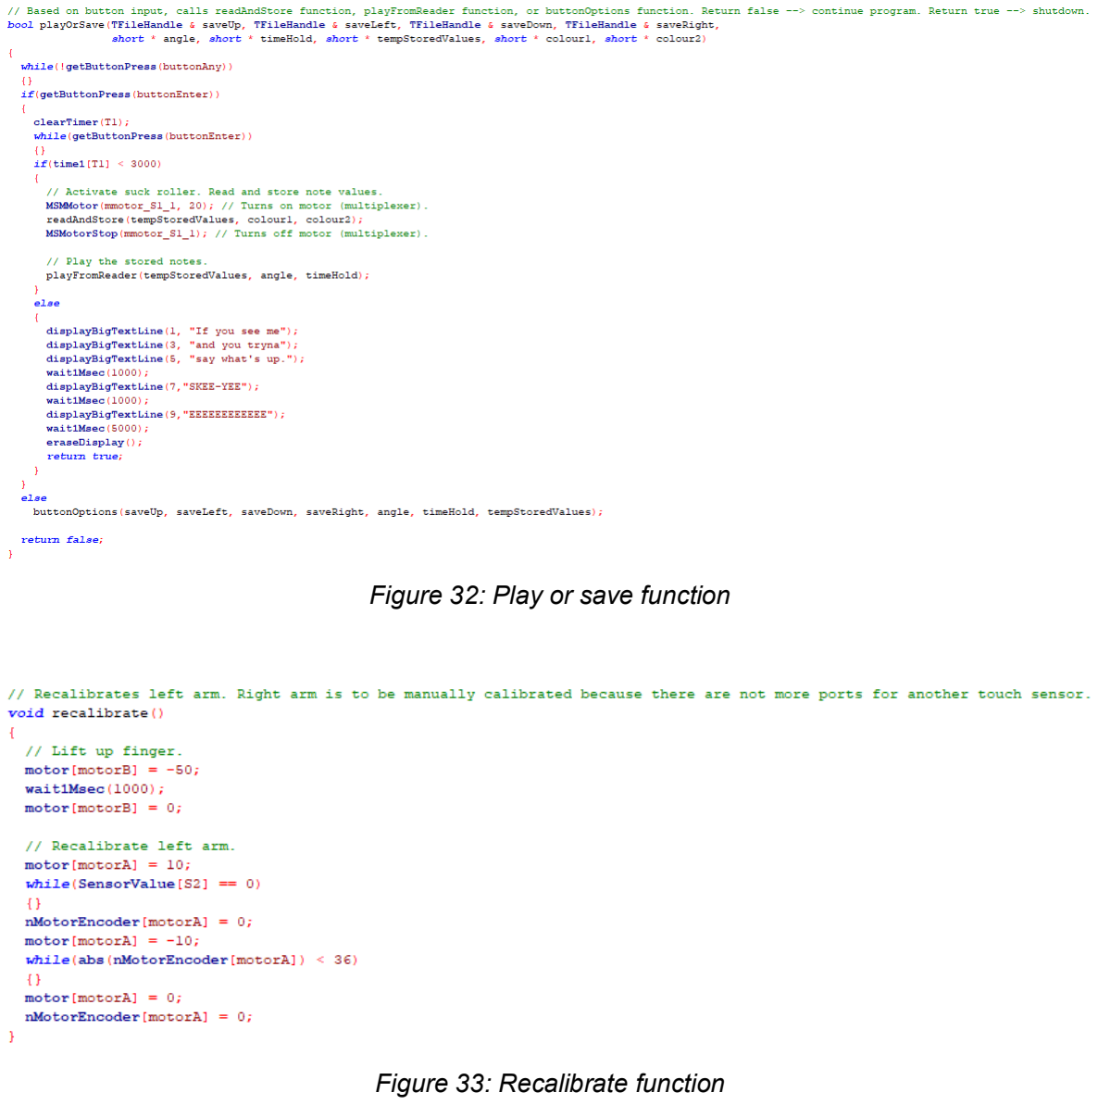
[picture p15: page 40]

Figure 32: Play or save function

Figure 33: Recalibrate function

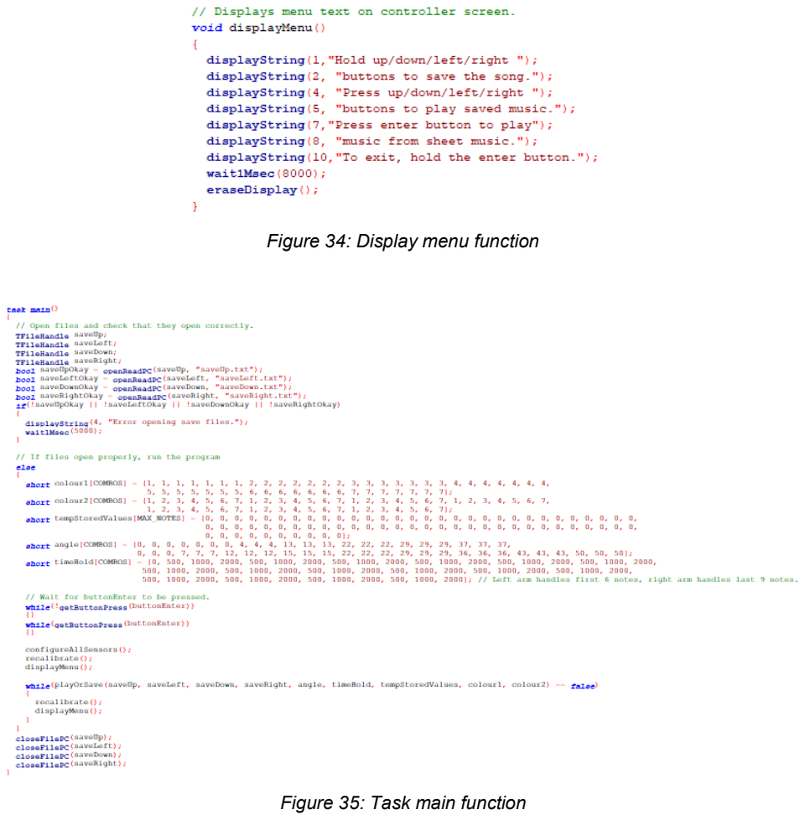
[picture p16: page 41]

Figure 34: Display menu function

Figure 35: Task main function

## Appendix B: CAD Models

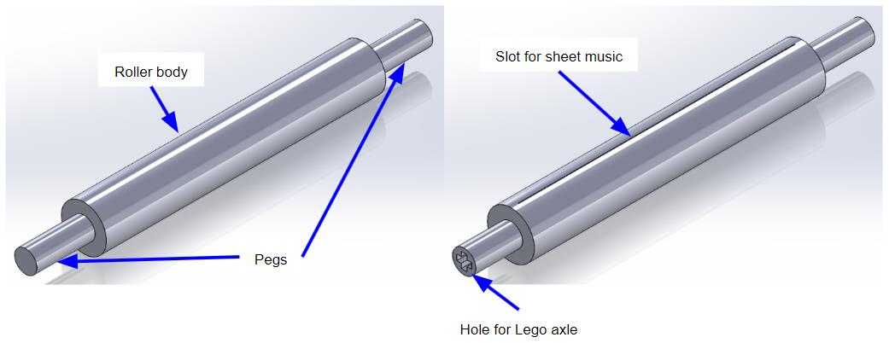
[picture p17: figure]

Figure 36: 3D CAD model of tensioning roller (left) and suck roller (right)

Figure 37: 3D CAD model of motor mount

Figure 38: SolidWorks assembly with motor mount, motor, Tetrix block, and nuts

Figure 39: AutoCAD drawing of color sensor bracket

Figure 40: AutoCAD drawing of finger

Figure 41: SolidWorks model of a medium Lego motor

Figure 42: SolidWorks model of a nut

Figure 43: SolidWorks model of a Tetrix block

## Appendix C: Software Flow Chart

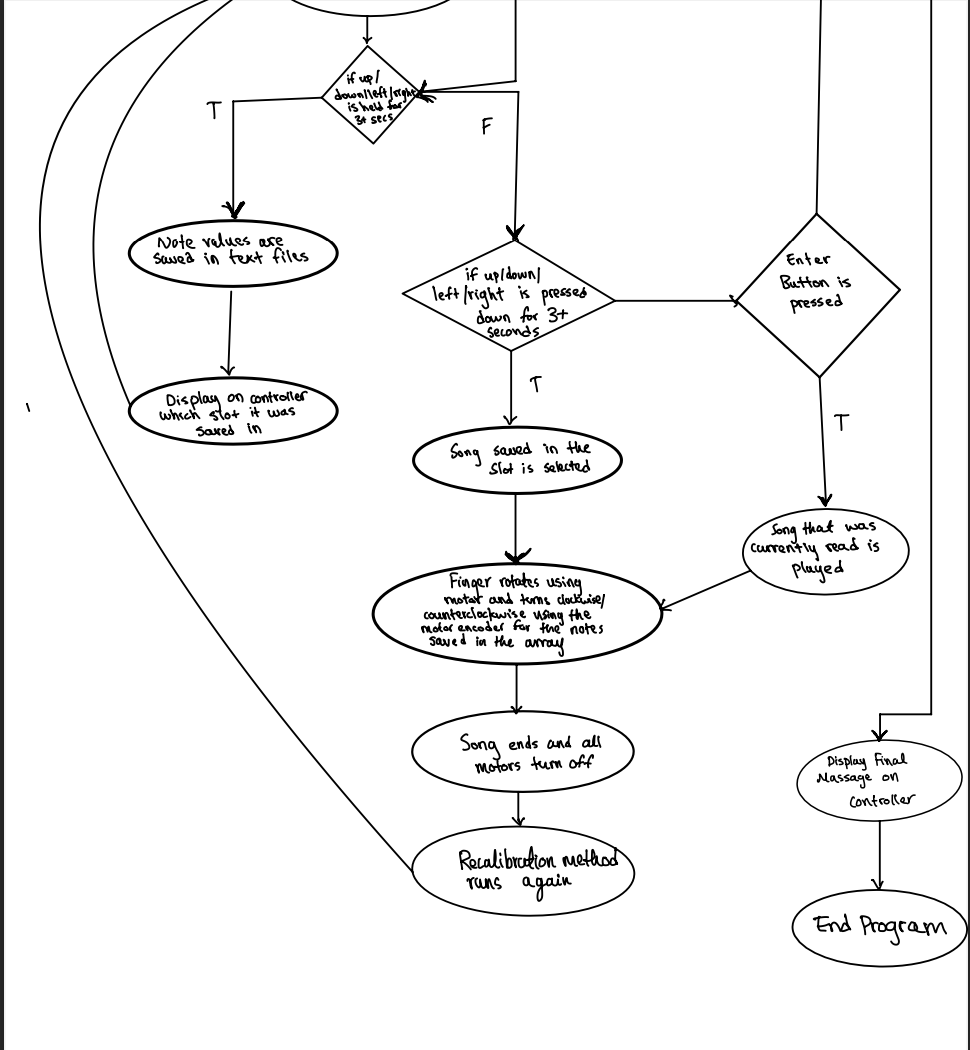
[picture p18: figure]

Figure 44: Software flow chart

## Appendix D: Robot Pictures

Figure 45: Color sensor bracket

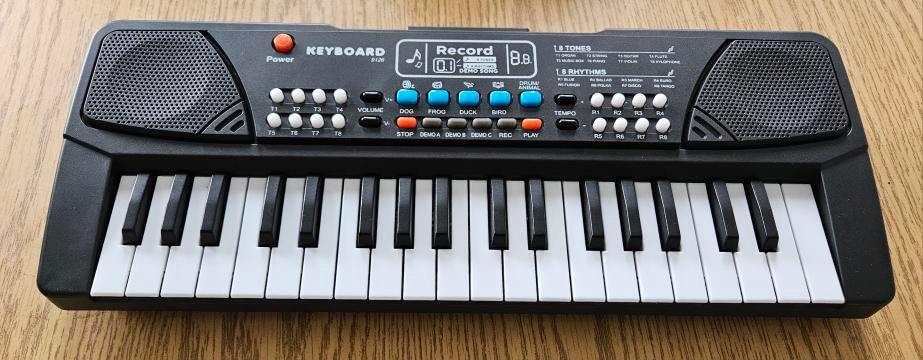
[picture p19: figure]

Figure 46: Electronic keyboard

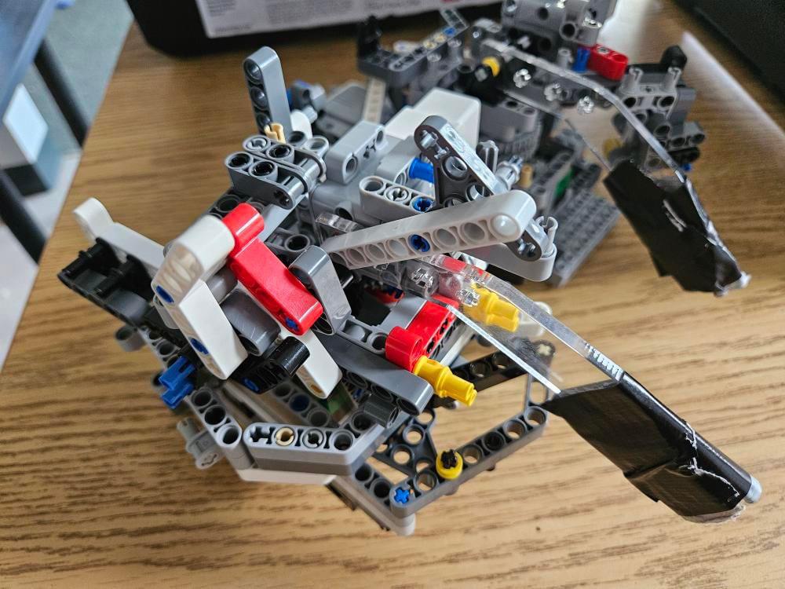
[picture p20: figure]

Figure 47: Note-playing section of robot

## Appendix E: Extra Sketches

Figure 48: A more detailed design of the horizontal rotation mechanism

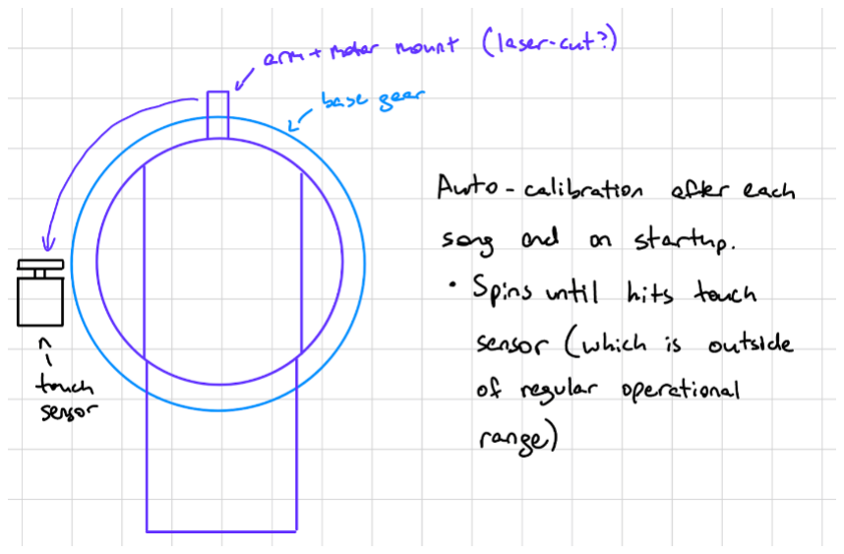
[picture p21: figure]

Figure 49: A conceptual sketch of the recalibration system

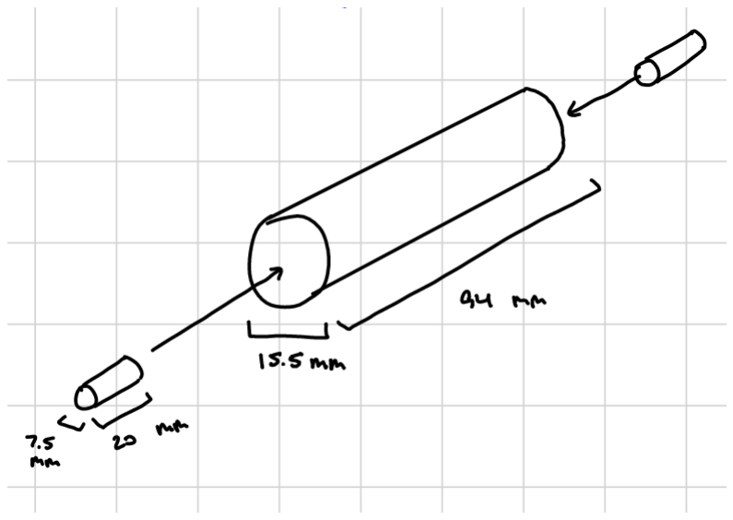
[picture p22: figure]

Figure 50: Dimensions for the rollers

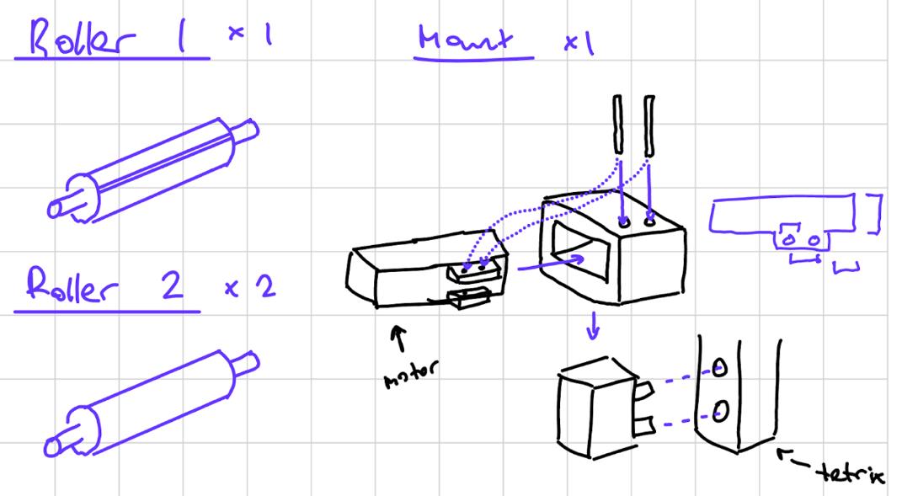
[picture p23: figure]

Figure 51: Sketches of the suck roller (roller 1), tensioning roller (roller 2), and motor mount

Figure 52: Color sensor bracket sketch

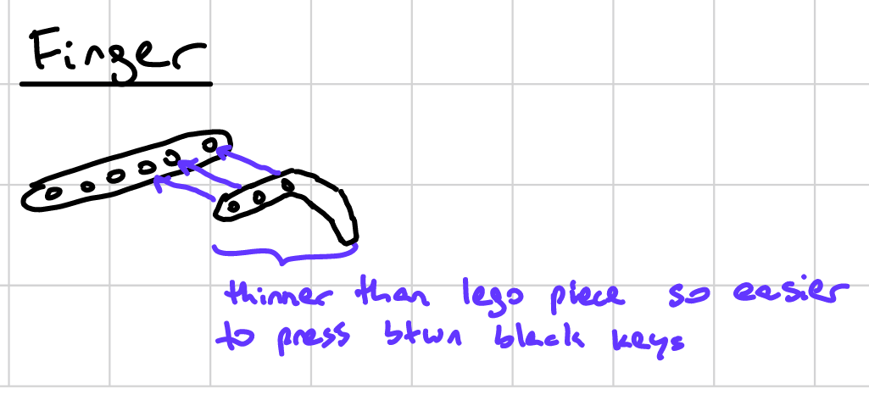
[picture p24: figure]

Figure 53: Finger sketch

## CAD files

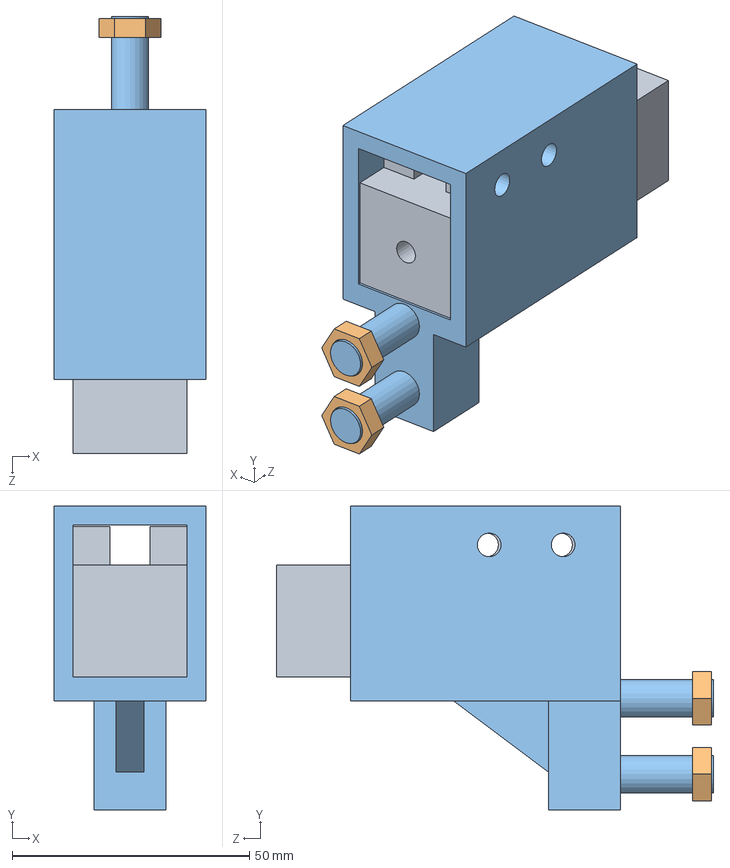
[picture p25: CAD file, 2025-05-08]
PianoBot CAD Files/Test Assy.SLDASM
32.0 x 64.1 x 92.2 mm
Motor Mount
Nut x 2
Motor Temp

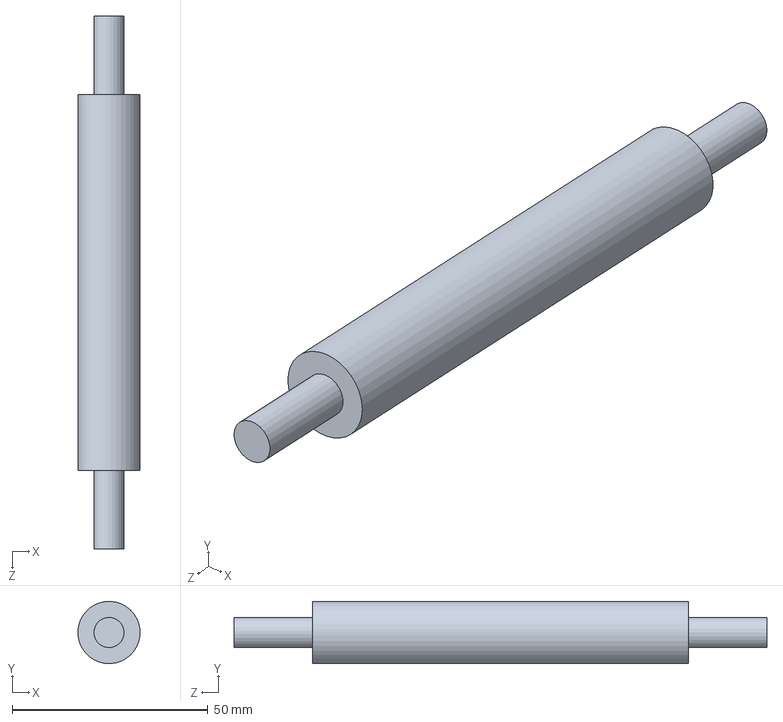
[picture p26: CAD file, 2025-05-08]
PianoBot CAD Files/Roller.SLDPRT
15.9 x 15.9 x 136.0 mm

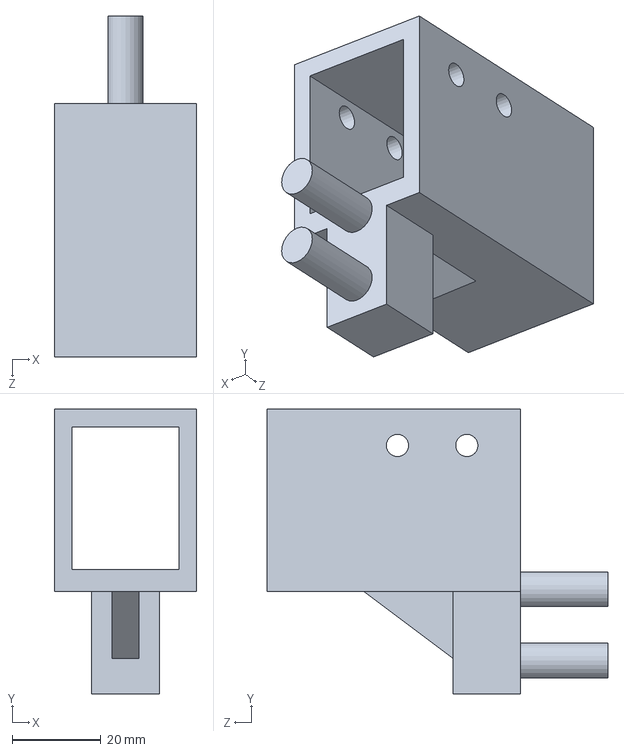
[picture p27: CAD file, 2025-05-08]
PianoBot CAD Files/Motor Mount.SLDPRT
32.0 x 64.1 x 76.6 mm

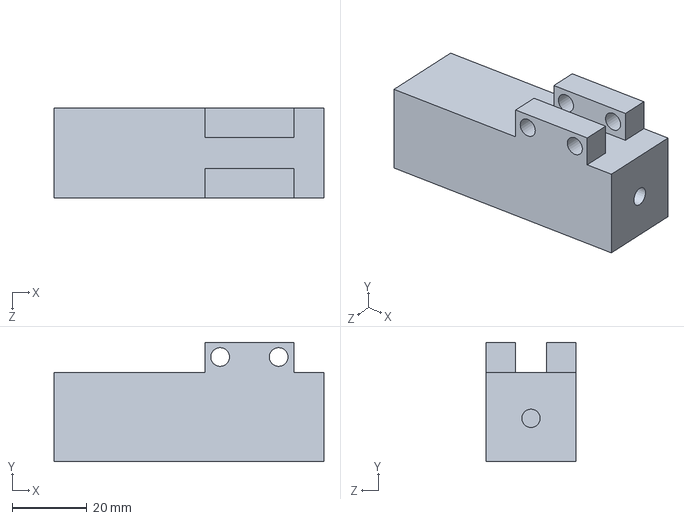
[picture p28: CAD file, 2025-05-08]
PianoBot CAD Files/Motor Temp.SLDPRT
72.0 x 31.8 x 24.0 mm

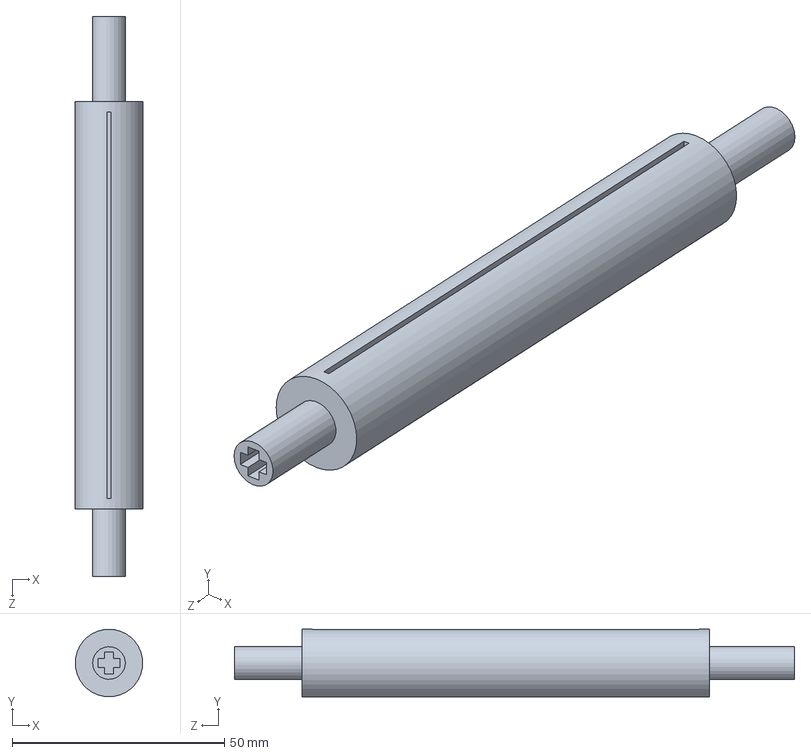
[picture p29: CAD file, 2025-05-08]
PianoBot CAD Files/Suck Roller.SLDPRT
15.9 x 15.9 x 131.9 mm

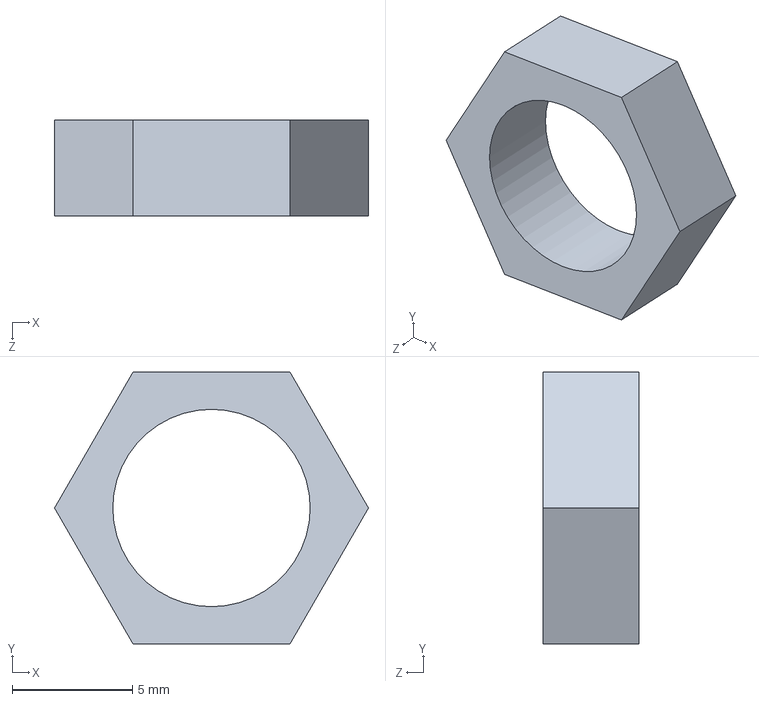
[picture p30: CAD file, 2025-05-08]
PianoBot CAD Files/Nut.SLDPRT
13.0 x 11.3 x 4.00 mm

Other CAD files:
PianoBot CAD Files/Motor Mount.STL
PianoBot CAD Files/Nut.STL
PianoBot CAD Files/Roller.STL
PianoBot CAD Files/Suck Roller.STL

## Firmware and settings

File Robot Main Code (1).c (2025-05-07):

const int COMBOS = 64;
const int MAX_NOTES = 100;

void configureAllSensors() // TO BE MODIFIED.
{
	SensorType[S1] = sensorEV3_Touch;
	SensorType[S2] = sensorEV3_Ultrasonic;
	SensorType[S3] = sensorEV3_Color;
	wait1Msec(50);
	SensorMode[S3] = modeEV3Color_Color;
	wait1Msec(50);
	SensorType[S4] = sensorEV3_Gyro;
	wait1Msec(50);
	SensorMode[S4] = modeEV3Gyro_Calibration;
	wait1Msec(100);
	SensorMode[S4] = modeEV3Gyro_RateAndAngle;
	wait1Msec(50);
}

void storeValue(int tempStoredValues[MAX_NOTES], int colour1[COMBOS], int colour2[COMBOS], int noteIndex)
{
	bool noteAchieved = false;
	for(int noteValue = 0; noteValue < COMBOS && noteAchieved == false; noteValue++)
	{
		if(SensorValue[S1] == colour1[noteValue] && SensorValue[S2] == colour2[noteValue])
		{
			tempStoredValues[noteIndex] = noteValue;
			noteAchieved = true;
		}
	}
}

void readAndStore(int tempStoredValues[MAX_NOTES], int colour1[COMBOS], int colour2[COMBOS])
{
	// Clear array
	for(int i = 0; i < MAX_NOTES; i++)
		tempStoredValues[i] = 0;

	int col_1 = 0, col_2 = 0;
	int noteIndex = 0;

	// While reading blank paper, do nothing.
	while(SensorValue[S1] == (int)colorWhite && SensorValue[S2] == (int)colorWhite)
	{}

	// While not reading white-white, continue reading and storing.
	while(SensorValue[S1] != (int)colorWhite && SensorValue[S2] != (int)colorWhite)
	{
		col_1 = SensorValue[S1];
		col_2 = SensorValue[S2];

		storeValue(tempStoredValues, colour1, colour2, noteIndex);
		noteIndex++;

		// While robot hasn't reached next set of colours, do nothing. Assume we don't have two same notes right after the other.
		while(SensorValue[S1] == col_1 && SensorValue[S2] == col_2)
		{}
	}
}

void playFromFile(ifstream & fin, int angle[COMBOS], int time[COMBOS]) // call this function in the save or play function
{
	int noteValue = 0; // note values stored in the txt file
	int angleOriginal = 0;
	int angleNew = 0;

	while (fin >> noteValue) // Assuming that nMotorEncoder = 0 at the leftmost position of the finger
	{
		angleNew = angle[noteValue];
		if(angleNew > angleOriginal) // go clockwise
		{
			motor[motorA] = 50; // change motorA to whatever motor we use to turn finger
			while(nMotorEncoder[motorA] != angleNew)
			{}
			motor[motorA] = 0;
			clearTimer[T1];
			motor[motorB] = 100;
			wait1Msec(time[noteValue]) // wait for the time stored in the note time array (might have to convert to milliseconds)
			motor[motorB] = -100;
			while(nMotorEncoder[motorA] > 0)
			{}
			motor[motorB] = 0;
		}
		else // go counterclockwise
		{
			motor[motorA] = -50; // change motorA to whatever motor we use to turn finger
			while(nMotorEncoder[motorA] != angleNew)
			{}
			motor[motorA] = 0;
			clearTimer[T1];
			motor[motorB] = 100;
			wait1Msec(time[noteValue]) // wait for the time stored in the note time array (might have to convert to milliseconds)
			motor[motorB] = -100;
			while(nMotorEncoder[motorA] > 0)
			{}
			motor[motorB] = 0;
		}
		angleOriginal = angleNew;
	}
}

void playFromReader(tempStoredValues[MAX_NOTES], int angle[COMBOS], int time[COMBOS])
{
	int noteValue = 0;
	int angleOriginal = 0;
	int angleNew = 0;

	for(int i = 0; i < MAX_NOTES && tempStoredValues[i] != 0; i++) // tempStoredValues[i] == 0 means end of song.
	{
		noteValue = tempStoredValues[i];
		angleNew = angle[noteValue];
		if(angleNew > angleOriginal) // go clockwise
		{
			motor[motorA] = 50; // change motorA to whatever motor we use to turn finger
			while(nMotorEncoder[motorA] != angleNew)
			{}
			motor[motorA] = 0;
			clearTimer[T1];
			motor[motorB] = 100;
			wait1Msec(time[noteValue]) // wait for the time stored in the note time array (might have to convert to milliseconds)
			motor[motorB] = -100;
			while(nMotorEncoder[motorA] > 0)
			{}
			motor[motorB] = 0;
		}
		else // go counterclockwise
		{
			motor[motorA] = -50; // change motorA to whatever motor we use to turn finger
			while(nMotorEncoder[motorA] != angleNew)
			{}
			motor[motorA] = 0;
			clearTimer[T1];
			motor[motorB] = 100;
			wait1Msec(time[noteValue]) // wait for the time stored in the note time array (might have to convert to milliseconds)
			motor[motorB] = -100;
			while(nMotorEncoder[motorA] > 0)
			{}
			motor[motorB] = 0;
		}
		angleOriginal = angleNew;
	}
}

void buttonOptions(ifstream & saveUp, ifstream & saveLeft, ifstream & saveDown, ifstream & saveRight, int angle[COMBOS], int time[COMBOS])
{
	if(getButtonPress(buttonUp))
	{
		while(getButtonPress(buttonUp))
		{}
		if(time1[T1] < 3000)
			playFromFile(saveUp, angle, time);
		else
			// Played song will be saved to that slot
	}

	if(getButtonPress(buttonLeft))
	{
		while(getButtonPress(buttonLeft))
		{}
		if(time1[T1] < 3000)
			playFromFile(saveLeft, angle, time);
		else
			// Played song will be saved to that slot
	}

	if(getButtonPress(buttonDown))
	{
		while(getButtonPress(buttonDown))
		{}
		if(time1[T1] < 3000)
			playFromFile(saveDown, angle, time);
		else
			// Played song will be saved to that slot
	}

	if(getButtonPress(buttonRight))
	{
		while(getButtonPress(buttonRight))
		{}
		if(time1[T1] < 3000)
			playFromFile(saveRight, angle, time);
		else
			// Played song will be saved to that slot
	}
}

void playOrSave(ifstream & saveUp, ifstream & saveLeft, ifstream & saveDown, ifstream & saveRight, int angle[COMBOS], int time[COMBOS], tempStoredValues[MAX_NOTES])
{
	while(!getButtonPress(buttonAny))
	{}
	clearTimer(T1);

	if(getButtonPress(buttonEnter))
	{
		while(getButtonPress(buttonEnter))
		{}
		if(time1[T1] < 3000)
		{
			// Activate suck roller. Read and store note values.
			motor[motorA] = 10; // replace motorA with whatever motor we use
			readAndStore(tempStoredValues, colour1, colour2);
			motor[motorA] = 0;

			// Play the stored notes.
			playFromReader(tempStoredValues, angle, time);
		}
		else
			// Shutdown procedure
	}
	else
		buttonOptions(saveUp, saveLeft, saveRight, saveDown, saveRight, angle, time, tempStoredValues);
}

void recalibrate()
{
	motor[motorA] = -10; // whatever motor we using
	while(SensorValue[S3] == 0) // change S3 to whatever sensor is plugged in
	{}
	nMotorEncoder[motorA] = 0;
	motor[motorA] = 10;
	while(nMotorEncoder[motorA] != xxxx) // xxxx is the angle to get to the leftmost note
	{}
	nMotorEncoder[motorA] = 0;
	motor[motorA] = 0;
}

void displayMenu()
{
	displayString(1,?Hold up/down/left/right buttons to save the song.?);
	displayString(2,Press up/down/left/right buttons to play saved music.?);
	displayString(3,?Press enter button to play music from sheet music.?);
	displayString(4,?To exit, hold the enter button.?);
	wait1Msec(5000);
	eraseDisplay();
}

void shutdownProcedure() // Need to figure this part out.
{
	eraseDisplay();
	displayBigTextLine(5,"Skee-yee");
	wait1Msec(5000); //Will end the program
}

task main()
{
	ifstream saveUp("saveUp.txt"); // Need to check how file saving works with robot controllers - video on learn
	ifstream saveLeft("saveLeft.txt");
	ifstream saveDown("saveDown.txt");
	ifstream saveRight("saveRight.txt");
	// check for file open

	int colour1[COMBOS] = {}; // to change
	int colour2[COMBOS] = {}; // to change
	int tempStoredValues[MAX_NOTES] = {}; // to change. a noteValue of 0 should correspond to white-white.
	int angle[COMBOS] = {}; // set these based on testing
	int timeHold[COMBOS] = {}; // to change

	configureAllSensors();
	recalibrate;
	displayMenu;

	while(true) // FIX
	{
		playOrSave(saveUp, saveLeft, saveDown, saveRight, angle, time, tempStoredValues);
		recalibrate;
		displayMenu;
	}



	saveUp.close(); // Close files and exit program.
	saveLeft.close();
	saveDown.close();
	saveRight.close();
}
